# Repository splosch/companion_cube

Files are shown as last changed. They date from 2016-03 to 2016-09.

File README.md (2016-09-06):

<br /><span xmlns:dct="http://purl.org/dc/terms/" property="dct:title">Companion Cube - Configurable Mold</span> by <a xmlns:cc="http://creativecommons.org/ns#" href="http://www.thxcube.com" property="cc:attributionName" rel="cc:attributionURL">Mario Winkler</a> is licensed under a <a rel="license" href="http://creativecommons.org/licenses/by-nc-sa/4.0/">Creative Commons Attribution-NonCommercial-ShareAlike 4.0 International License</a>.

# Companion Cube - a modular mold
... resulting in a 80 x 80 x 80 mm concrete-cube wich weights ~1.000 gramms.
This project aims to provide and improve a reusable, modular and configurable, 3D-printable mold, out of which a solid brick can be released.

It's meant to be come out rough and basic, but with nicly angled, concrete-loving edges.
A simple system keeps all the parts of the mold in place, tight enough to allow even viscous concrete to cure without leakage.

## About
### Whats the cube for?
Initially the cube is meant to be a solid, handcrafted gift for people you care about, like collegues, friends and family.

### Configurable / Modular
3D-Printed logos, graphics, text or placeholder can be added (e.g. glued) to the side-walls of the mold. These "placeholders" can be pulled out of the concrete block once the initial curing is done.
See tips & tricks in the readme or example folder for propper design of these elements, so you can actually remove them later on.

I preferred weaker glue so in case the pieces get stuck, at least the wall can be released and the a carefull leftover removal can be done

## Preparation
## Printing the pieces
* the parts have been created with Printing-Process-Restrictions in mind.
  * no support structure needed
* Settings to produce good results
  * layer-height 0.1 - 0.15 (bigger will consume all of the 0.1 mm part-spacing)
  * 0.4 nozzle is fine
  * heated bed / fan is helpfull
  * PLA works perfectly since grease / oil / water / spray-paint wont harm it, and sanding can be done to reduce printed ripples
  * the basic mold parts should be printed as strong as possible
    * min. 35% infill (50% infilled parts might survive about 5-10 casts)
    * min. 1.2mm walls
    * stronger is better, since demolding can be slightly forcefull

  * print the 4 side-walls in one row using the side_wall_quadro.stl, they stabilize each other and no overhang issues occur
    * carefully tilting the 4 connected pieces, repeatingly will separate them eventually

## How-to create one brick
### Tools / Material
* nicely fitting (assembled) mold, with attached (glued) modifications
  * opt. mold-release agent (e.g. WD40, Silikon Spray, Butter)
* a spoon, tough one
* a bowl to mix the concrete (volume 1 to 1.5 liters)
* tap-water in a bottle
* ~ 1.5kg finegrain concrete
  * up to 8 mm grain size
  * fast-curing helps
  * "add-water-only-concrete"
* a scale (with tara / tare option)
* optional mold-release agent (e.g. Silikon Spray, some oil or Butter)
* optional but recomended dust-protection for your mouth, gloves

### Mix it / pour it
* make sure the top is covered by the top_plate_inset
  * tape or rubberband helps keeping things in place
  * turn it around so the top becomes the bottom
* opt. apply release agent
* pre-calculate the amount of water required for 1.5 kg according to the concrete-package
* mix concrete calculated amount of water
  * stirr it equally - should not be too liquid, rather sticky
    * the pefect mix will not release any water
  * pour it spoon by spoon into the mold
  * if the concrete touches edges or modifications, tap / rattle gently on the walls to remove air-bubbles on the edges
  * fill until the the concrete touches the upper end of the 45deg inner edge of the plate
  * smoothen the surface, tapping the walls

# Troubleshooting
* pieces dont fit at all
  * please check wall orientation
  * any support-structure needs to be avoided or removed / sanded
  * your printer might have over-extrusion

* pieces fit too tight, break during assembly
  * check alignment
  * sand the connecting edges
  * move the pieces gently, to cause some wear

* demolding sucks
  * yes it does, but your mold will release easier with every cast
  * tap (with the spoon...) , gently on all edges to cause small movement
* walls bended a little
  * the concrete curing exposes heat, this could cause deformation of the PLA

  * the pieces have a 0.1 mm tolerance to conecting sides and parts, that will care for occuring printing tolerances
    * if the pieces fit too tight and tend to break, you can sand the edges a little with 120 / 240 sanding-paper

# Licencing
This project and all files are released under Licence
[Creative Commons Attribution-NonCommercial-ShareAlike 4.0 International License](http://creativecommons.org/licenses/by-nc-sa/4.0/)

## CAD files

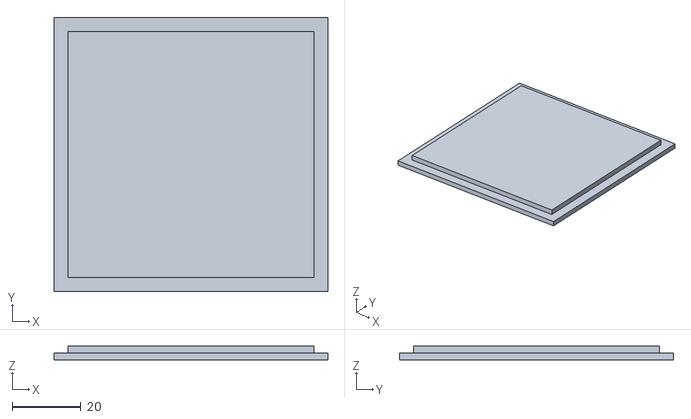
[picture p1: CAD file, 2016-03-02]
parts/top_plate_inset.stl
80.0 x 80.0 x 4.10

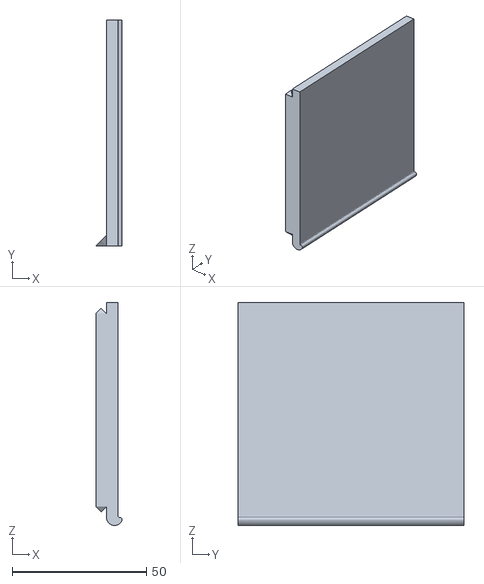
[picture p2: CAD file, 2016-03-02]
parts/side_wall.stl
9.84 x 84.1 x 83.0

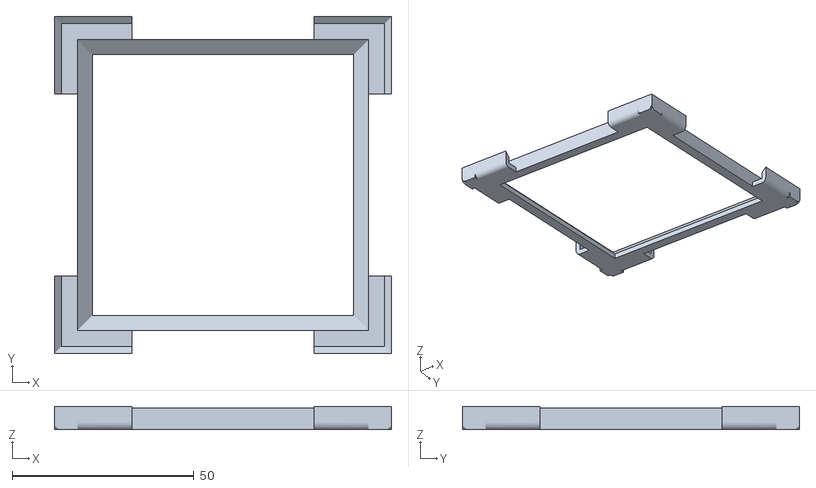
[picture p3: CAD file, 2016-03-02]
parts/top_plate.stl
92.8 x 92.8 x 6.40

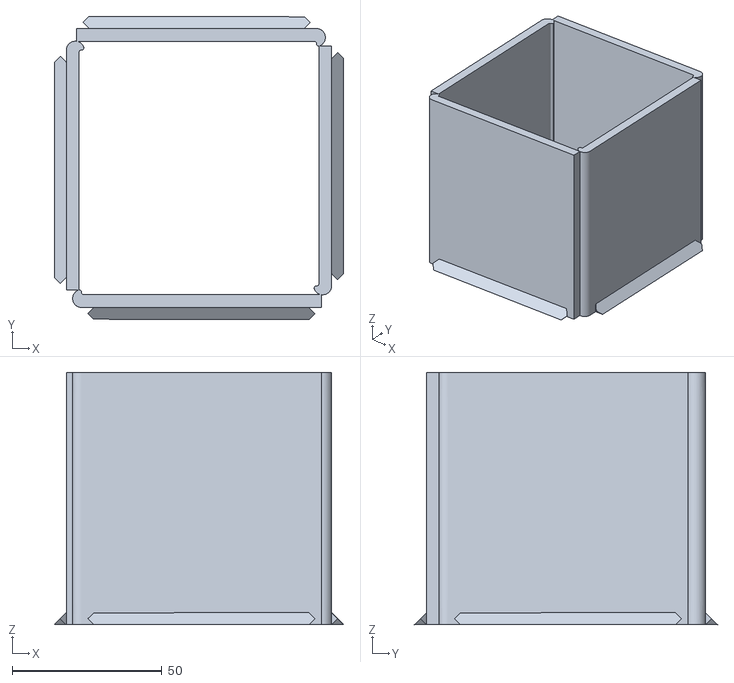
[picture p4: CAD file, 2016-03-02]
parts/side_wall_quadro.stl
96.5 x 101.1 x 84.1

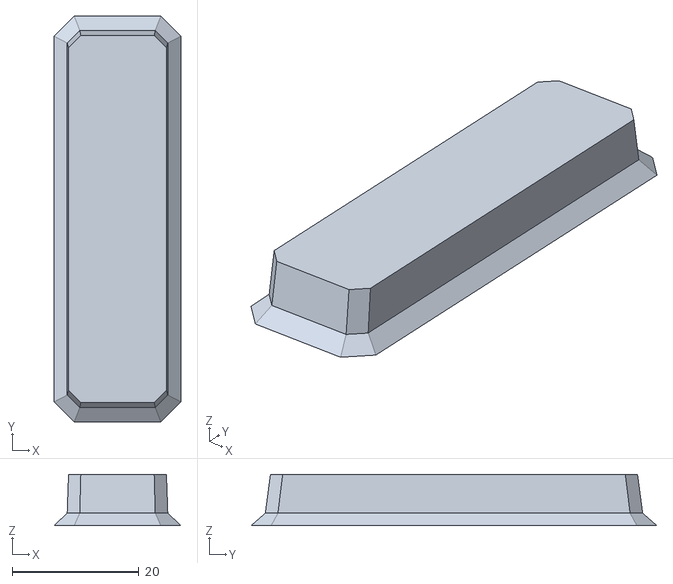
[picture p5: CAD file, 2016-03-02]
parts/spacer.stl
20.0 x 64.0 x 8.10

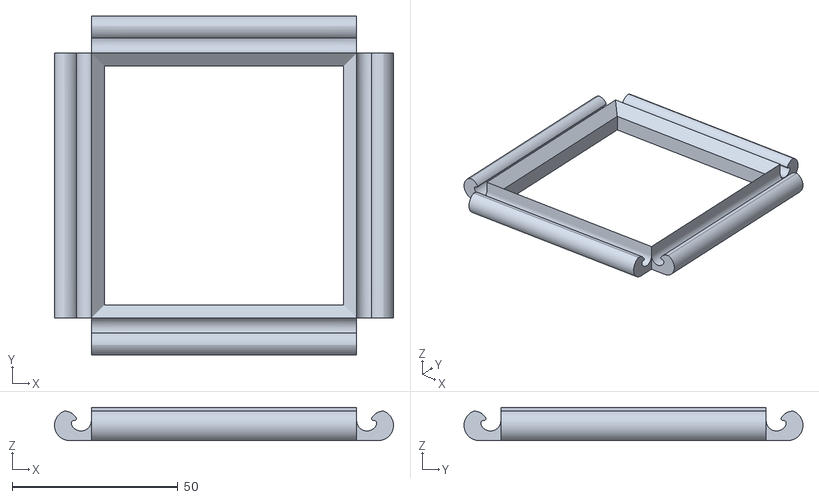
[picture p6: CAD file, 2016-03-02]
parts/hinge_plate.stl
102.2 x 102.2 x 10.0

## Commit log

2016-03-02 Companion Cube - Configurable Mold - v0 * cleanup files for opensourcing * readme with basic project and licence information * extract parts in parts folder + generate .stl * design, iterations on me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
    [hinge_plate.stl, side_wall.stl, side_wall_quadro.stl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]
2016-03-02 Correct spacer baseplate
